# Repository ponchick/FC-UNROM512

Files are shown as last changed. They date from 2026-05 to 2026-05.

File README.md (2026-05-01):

# FC-UNROM512

UNROM512 Famicom cartridge PCB (UNROM/UOROM family, extended PRG-ROM bank switching).

Russian version: [`README.ru.md`](README.ru.md)

More details about UNROM512 format and compatibility:

- [NESdev Wiki - UNROM 512](https://www.nesdev.org/wiki/UNROM_512)
- [NESdev Wiki mirror - UNROM 512](https://nesdev-wiki.nes.science/wikipages/UNROM_512.xhtml)

---

## Jumpers (board configuration)

### 1) Flash memory mode (write protection / self-flashing)

| Configuration | `FLASHLOCKED1`-`FLASHLOCKED4` | `FLASHABLE` | 74*139 | Bus conflicts |
| :--- | :---: | :---: | :---: | :---: |
| **Not Flashable** (write-protected) | Closed | Open | Not installed | **Present** |
| **Flashable** (self-flashable) | Open | Closed | Installed | **Absent** |

---

### 2) Mirroring

**Mirroring must match the ROM you are programming.** The game expects a specific mode (vertical/horizontal/1-screen). A wrong setting causes visual glitches.

Only one of these jumpers should be closed. For **Vertical mirroring**, close `VERTICAL` and keep `HORIZONTAL` and `ONE` open.

---

### 3) CHR RAM size configuration (8/16/32 KiB)

**The actual CHR RAM size is defined by the physical RAM chip** (for example, 62256 = 32 KiB). Jumpers only route the required address lines.

| Size | `CHR RAM 8k` | `CHR RAM 8k/16k` | `CHR RAM 16k/32k` | `CHR RAM 32k` |
| :--- | :---: | :---: | :---: | :---: |
| 8 KiB | Closed | Closed | Open | Open |
| 16 KiB | Open | Closed | Closed | Open |
| 32 KiB | Open | Open | Closed | Closed |

> **Use smaller CHR RAM sizes (8/16 KiB) only if the target ROM explicitly supports them.** Most UNROM512 / Mapper 30 software expects 32 KiB. Forcing a smaller size on unsupported ROMs can cause errors.

---

## License

This project is licensed under CERN Open Hardware Licence Version 2 - Permissive (`CERN-OHL-P-2.0`), see `LICENSE`.

SPDX-License-Identifier: `CERN-OHL-P-2.0`

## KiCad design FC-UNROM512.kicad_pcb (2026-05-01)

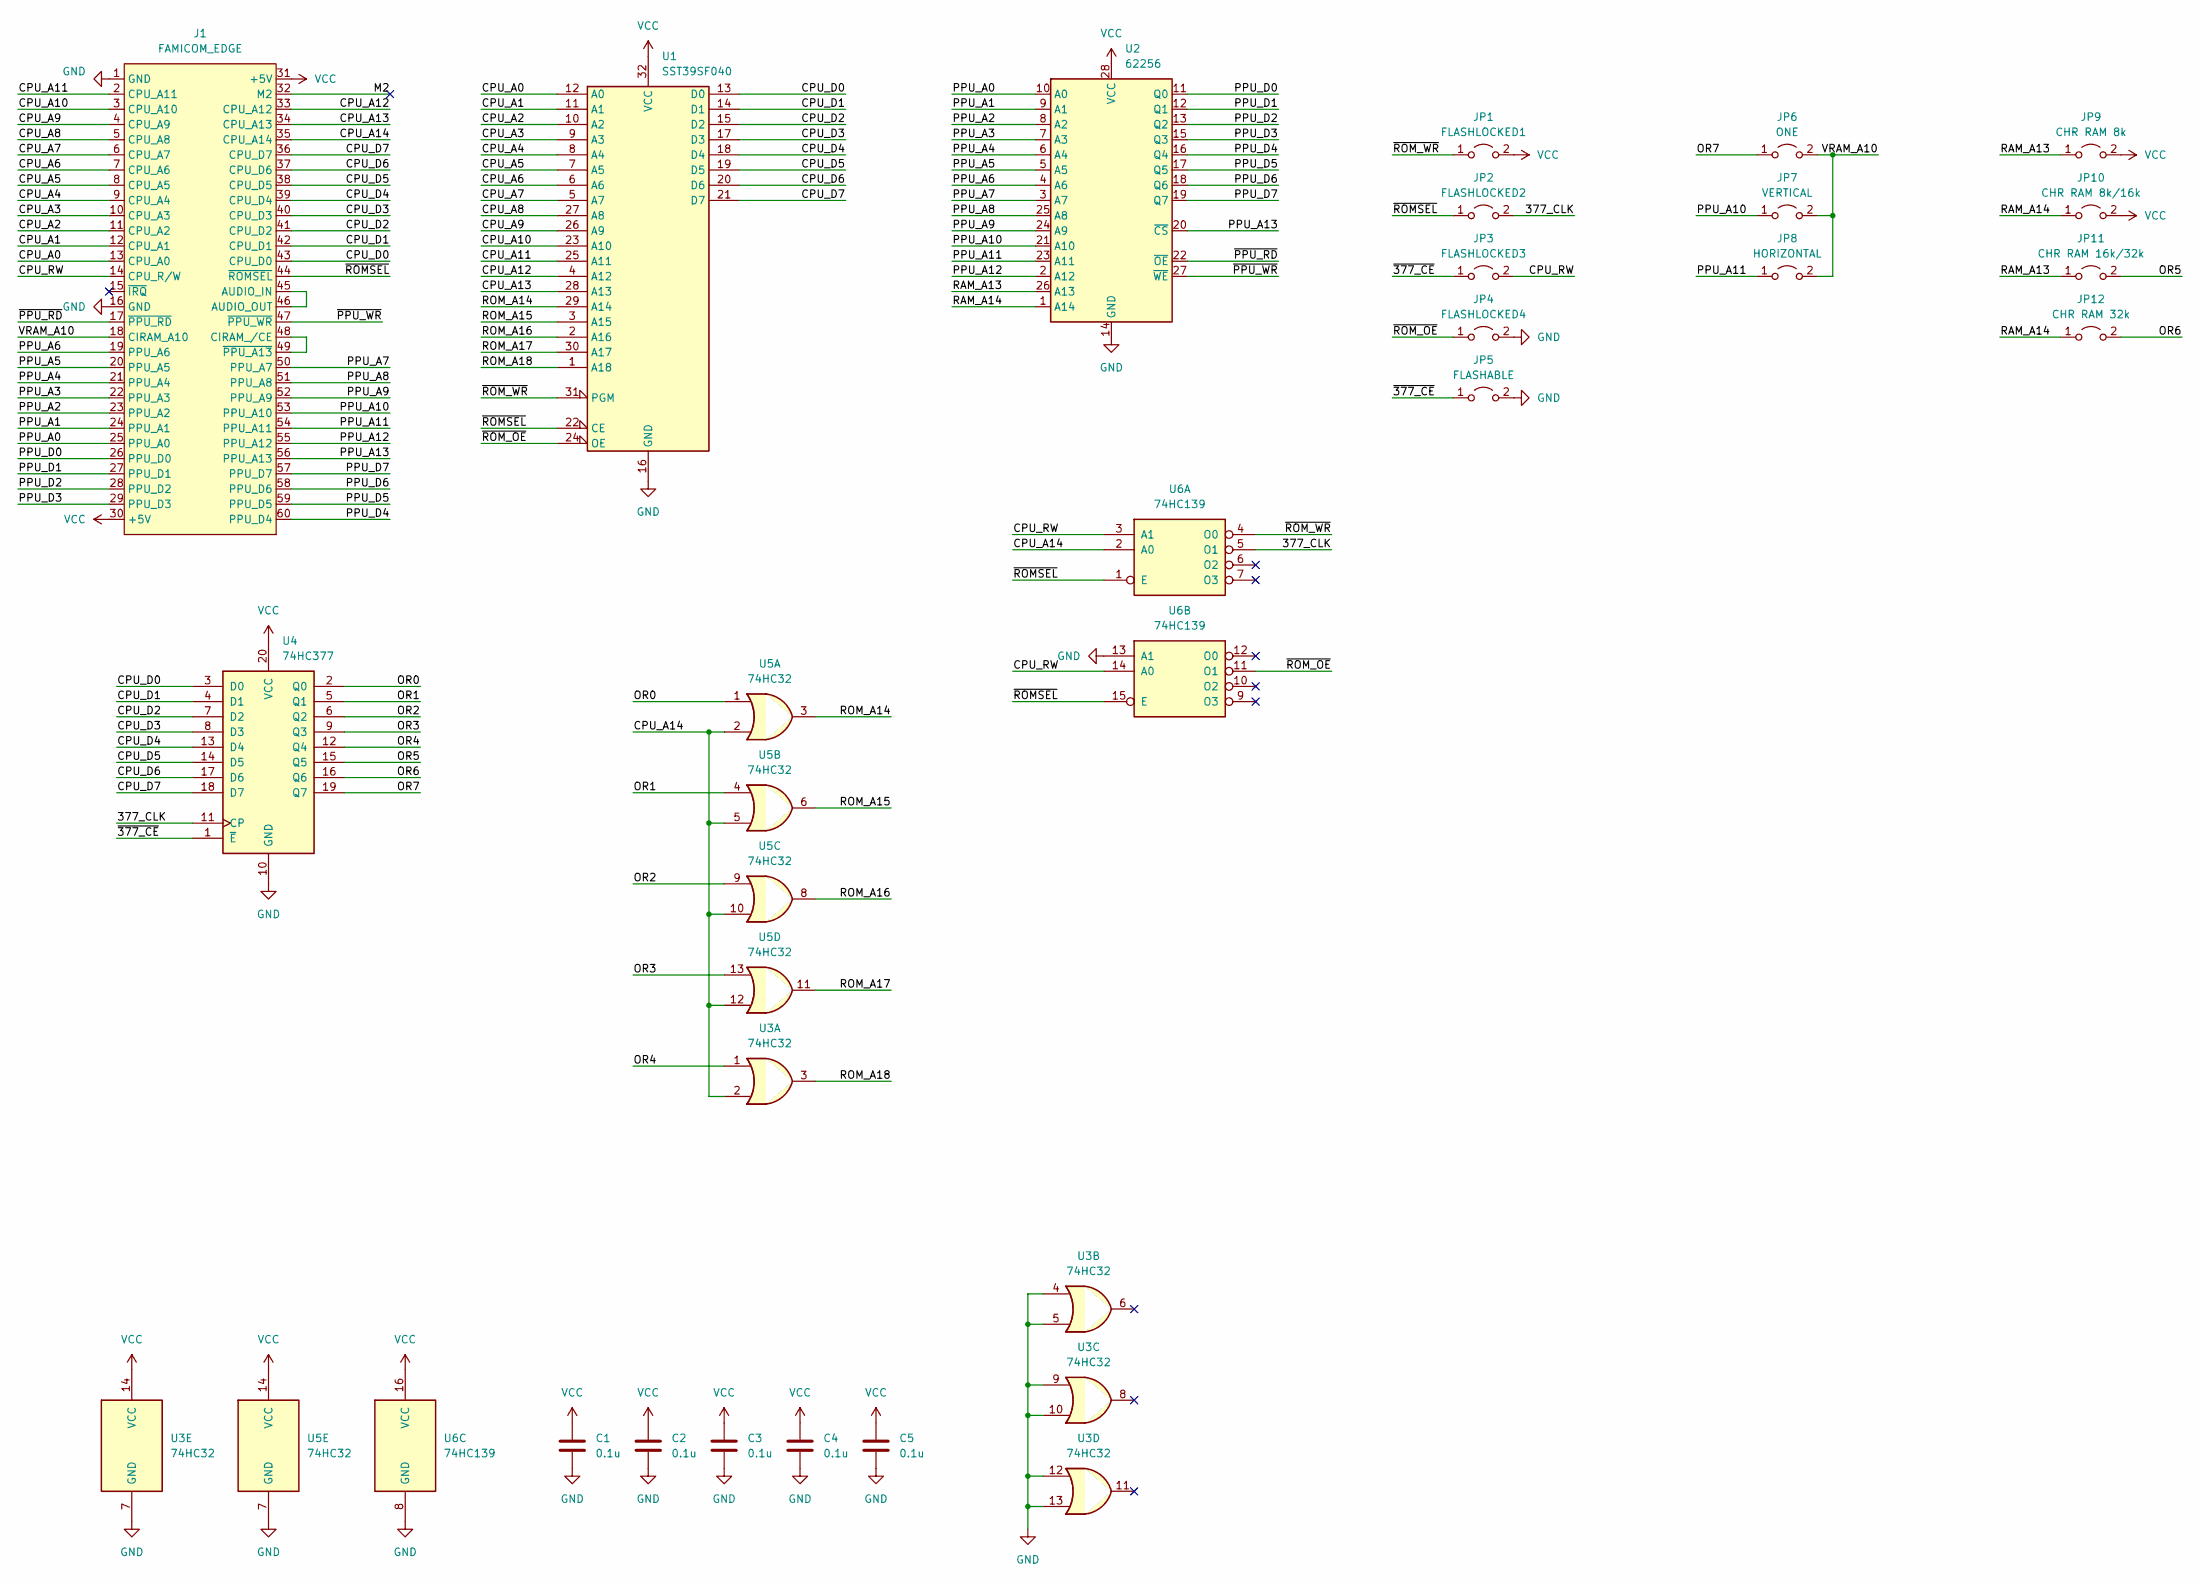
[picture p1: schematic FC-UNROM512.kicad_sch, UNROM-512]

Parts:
C1, C2, C3, C4, C5: 0.1u; C_Disc_D4.3mm_W1.9mm_P5.00mm
J1: FAMICOM_EDGE; CONN_EDGE_2x60
JP1: FLASHLOCKED1; SolderJumper-2_P1.3mm_Open_Pad1.0x1.5mm
JP2: FLASHLOCKED2; SolderJumper-2_P1.3mm_Open_Pad1.0x1.5mm
JP3: FLASHLOCKED3; SolderJumper-2_P1.3mm_Open_Pad1.0x1.5mm
JP4: FLASHLOCKED4; SolderJumper-2_P1.3mm_Open_Pad1.0x1.5mm
JP5: FLASHABLE; SolderJumper-2_P1.3mm_Open_Pad1.0x1.5mm
JP6: ONE; SolderJumper-2_P1.3mm_Open_Pad1.0x1.5mm
JP7: VERTICAL; SolderJumper-2_P1.3mm_Open_Pad1.0x1.5mm
JP8: HORIZONTAL; SolderJumper-2_P1.3mm_Open_Pad1.0x1.5mm
JP9: CHR RAM 8k; SolderJumper-2_P1.3mm_Open_Pad1.0x1.5mm
JP10: CHR RAM 8k/16k; SolderJumper-2_P1.3mm_Open_Pad1.0x1.5mm
JP11: CHR RAM 16k/32k; SolderJumper-2_P1.3mm_Open_Pad1.0x1.5mm
JP12: CHR RAM 32k; SolderJumper-2_P1.3mm_Open_Pad1.0x1.5mm
U1: SST39SF040; DIP-32_W15.24mm_Socket
U2: 62256; DIP-28_Dual
U3, U5: 74HC32; DIP-14_W7.62mm
U4: 74HC377; DIP-20_W7.62mm
U6: 74HC139; DIP-16_W7.62mm

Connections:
/377_CLK: JP2.2 (B), U4.11 (CP), U6.5 (O1)
/CPU_A0: J1.13 (CPU_A0), U1.12 (A0)
/CPU_A1: J1.12 (CPU_A1), U1.11 (A1)
/CPU_A2: J1.11 (CPU_A2), U1.10 (A2)
/CPU_A3: J1.10 (CPU_A3), U1.9 (A3)
/CPU_A4: J1.9 (CPU_A4), U1.8 (A4)
/CPU_A5: J1.8 (CPU_A5), U1.7 (A5)
/CPU_A6: J1.7 (CPU_A6), U1.6 (A6)
/CPU_A7: J1.6 (CPU_A7), U1.5 (A7)
/CPU_A8: J1.5 (CPU_A8), U1.27 (A8)
/CPU_A9: J1.4 (CPU_A9), U1.26 (A9)
/CPU_A10: J1.3 (CPU_A10), U1.23 (A10)
/CPU_A11: J1.2 (CPU_A11), U1.25 (A11)
/CPU_A12: J1.33 (CPU_A12), U1.4 (A12)
/CPU_A13: J1.34 (CPU_A13), U1.28 (A13)
/CPU_A14: J1.35 (CPU_A14), U3.2, U5.2, U5.5, U5.10, U5.12, U6.2 (A0)
/CPU_D0: J1.43 (CPU_D0), U1.13 (D0), U4.3 (D0)
/CPU_D1: J1.42 (CPU_D1), U1.14 (D1), U4.4 (D1)
/CPU_D2: J1.41 (CPU_D2), U1.15 (D2), U4.7 (D2)
/CPU_D3: J1.40 (CPU_D3), U1.17 (D3), U4.8 (D3)
/CPU_D4: J1.39 (CPU_D4), U1.18 (D4), U4.13 (D4)
/CPU_D5: J1.38 (CPU_D5), U1.19 (D5), U4.14 (D5)
/CPU_D6: J1.37 (CPU_D6), U1.20 (D6), U4.17 (D6)
/CPU_D7: J1.36 (CPU_D7), U1.21 (D7), U4.18 (D7)
/CPU_RW: J1.14 (CPU_R/W), JP3.2 (B), U6.3 (A1), U6.14 (A0)
/M2: J1.32 (M2)
/OR0: U4.2 (Q0), U5.1
/OR1: U4.5 (Q1), U5.4
/OR2: U4.6 (Q2), U5.9
/OR3: U4.9 (Q3), U5.13
/OR4: U3.1, U4.12 (Q4)
/OR5: JP11.2 (B), U4.15 (Q5)
/OR6: JP12.2 (B), U4.16 (Q6)
/OR7: JP6.1 (A), U4.19 (Q7)
/PPU_A0: J1.25 (PPU_A0), U2.10 (A0)
/PPU_A1: J1.24 (PPU_A1), U2.9 (A1)
/PPU_A2: J1.23 (PPU_A2), U2.8 (A2)
/PPU_A3: J1.22 (PPU_A3), U2.7 (A3)
/PPU_A4: J1.21 (PPU_A4), U2.6 (A4)
/PPU_A5: J1.20 (PPU_A5), U2.5 (A5)
/PPU_A6: J1.19 (PPU_A6), U2.4 (A6)
/PPU_A7: J1.50 (PPU_A7), U2.3 (A7)
/PPU_A8: J1.51 (PPU_A8), U2.25 (A8)
/PPU_A9: J1.52 (PPU_A9), U2.24 (A9)
/PPU_A10: J1.53 (PPU_A10), JP7.1 (A), U2.21 (A10)
/PPU_A11: J1.54 (PPU_A11), JP8.1 (A), U2.23 (A11)
/PPU_A12: J1.55 (PPU_A12), U2.2 (A12)
/PPU_A13: J1.56 (PPU_A13), U2.20 (~CS)
/PPU_D0: J1.26 (PPU_D0), U2.11 (Q0)
/PPU_D1: J1.27 (PPU_D1), U2.12 (Q1)
/PPU_D2: J1.28 (PPU_D2), U2.13 (Q2)
/PPU_D3: J1.29 (PPU_D3), U2.15 (Q3)
/PPU_D4: J1.60 (PPU_D4), U2.16 (Q4)
/PPU_D5: J1.59 (PPU_D5), U2.17 (Q5)
/PPU_D6: J1.58 (PPU_D6), U2.18 (Q6)
/PPU_D7: J1.57 (PPU_D7), U2.19 (Q7)
/RAM_A13: JP9.1 (A), JP11.1 (A), U2.26 (A13)
/RAM_A14: JP10.1 (A), JP12.1 (A), U2.1 (A14)
/ROM_A14: U1.29 (A14), U5.3
/ROM_A15: U1.3 (A15), U5.6
/ROM_A16: U1.2 (A16), U5.8
/ROM_A17: U1.30 (A17), U5.11
/ROM_A18: U1.1 (A18), U3.3
/VRAM_A10: J1.18 (CIRAM_A10), JP6.2 (B), JP7.2 (B), JP8.2 (B)
/~377_CE: JP3.1 (A), JP5.1 (A), U4.1 (~E)
/~PPU_RD: J1.17 (~PPU_RD), U2.22 (~OE)
/~PPU_WR: J1.47 (~PPU_WR), U2.27 (~WE)
/~ROMSEL: J1.44 (~ROMSEL), JP2.1 (A), U1.22 (CE), U6.1 (E), U6.15 (E)
/~ROM_OE: JP4.1 (A), U1.24 (OE), U6.11 (O1)
/~ROM_WR: JP1.1 (A), U1.31 (PGM), U6.4 (O0)
GND: C1.2, C2.2, C3.2, C4.2, C5.2, J1.1 (GND), J1.16 (GND), JP4.2 (B), JP5.2 (B), U1.16 (GND), U2.14 (GND), U3.4, U3.5, U3.7 (GND), U3.9, U3.10, U3.12, U3.13, U4.10 (GND), U5.7 (GND), U6.8 (GND), U6.13 (A1)
unnamed: J1.45 (AUDIO_IN), J1.46 (AUDIO_OUT)
unnamed: J1.48 (CIRAM_/CE), J1.49 (~PPU_A13)
VCC: C1.1, C2.1, C3.1, C4.1, C5.1, J1.30 (+5V), J1.31 (+5V), JP1.2 (B), JP9.2 (B), JP10.2 (B), U1.32 (VCC), U2.28 (VCC), U3.14 (VCC), U4.20 (VCC), U5.14 (VCC), U6.16 (VCC)

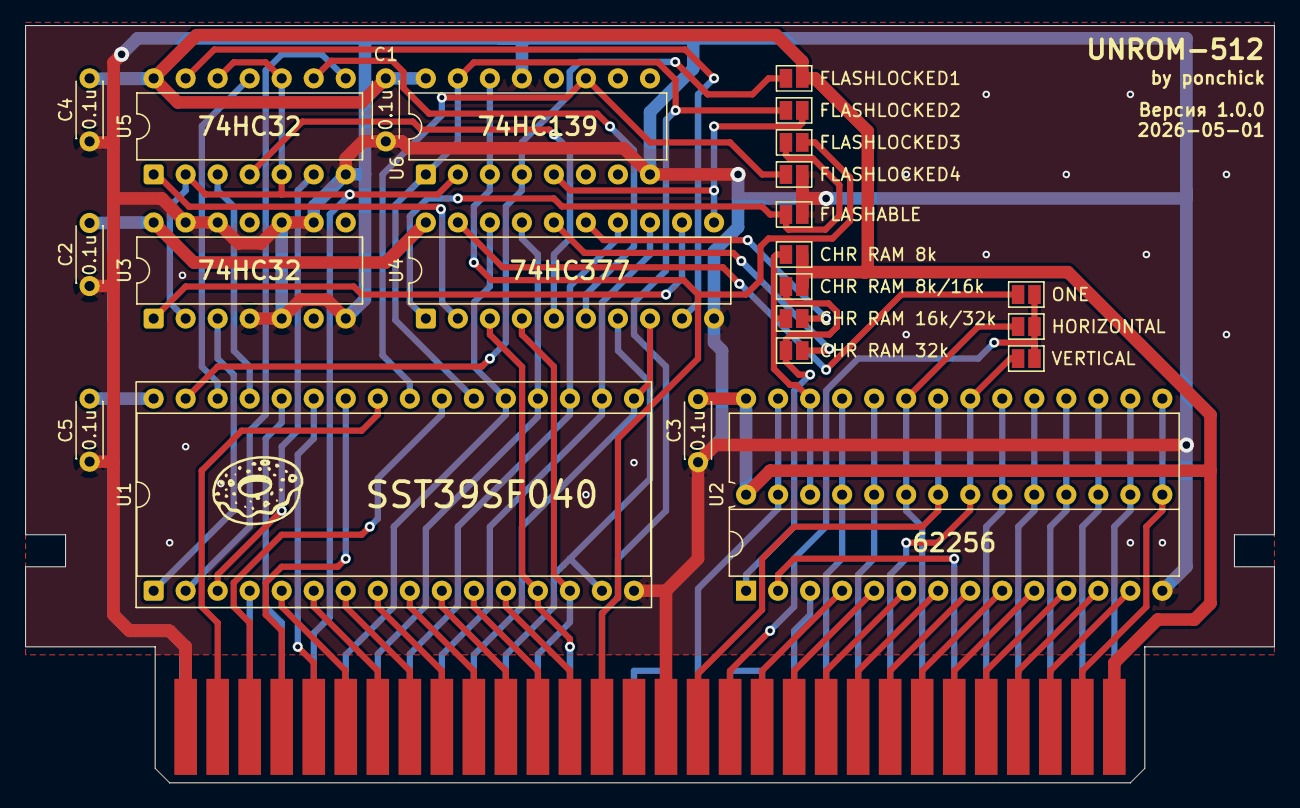
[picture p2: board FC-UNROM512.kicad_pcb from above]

Board: 2 copper layers, 99.1 x 60.1 mm, 25 parts (0 on the bottom side), 73 nets.

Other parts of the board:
LOGO#: LOGO; ponchick
